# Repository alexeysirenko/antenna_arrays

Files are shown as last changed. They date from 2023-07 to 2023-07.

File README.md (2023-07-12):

# Комплект для використання KrakenSDR в польових умовах

Конструкція розроблялась в напівпольових умовах при відсутності нормальної майстерні, задля того щоб перевірити працездатність ідеї використання KrakenSDR для військових потреб, в тому числі задля перевірки точності. Через це конструкція має дещо кустарний вигляд (термоклей, ізолента тощо), але при цьому її легко відтворити маючи прямі руки і мінімум інструментів. При цьому все ще лишається великий простір для вдосконалення, наприклад непогано було б прикрутити герметичний Ethernet та силовий роз'єми до корпусу замість нерозборного варіанту з кабелями як зараз.

Комплект умовно ділиться на компоненти:
- <a href="/dipoles">Диполі (5+2) та фідерні лінії</a>
- <a href="/linear_array">Траверса та кріплення до мачти</a>
- <a href="/box">Гермобокс</a>

## Що можна покращити

- додати герметичні роз'єми для Ethernet та живлення (силовий роз'єм) на корпус, щоб кабелі легко було замінити
- примусове охолодження гермобокса. Самий простий варіант - кулер + терморезистор. Але це потрібно лише влітку, в інші пори року бокс має бути герметичним, тобто потрібна можливість закривати та відкривати воздухозаборники
- виніс траверси від мачти можна зробити на 50 мм далі
- потрібен режим енергозбереження. Простий варіант - реле, котре відключає подачу 220в на блок живлення KrakenSDR, управляється з пінів Raspberry
- передачу даних від Raspberry до клієнта можна зробити через модулі LoRa або Motorola+Bluetooth, тобто потрібен окремий пристрій, але він суттєво здешевить конструкцію (не потрібен буде Starlink)

## Галерея

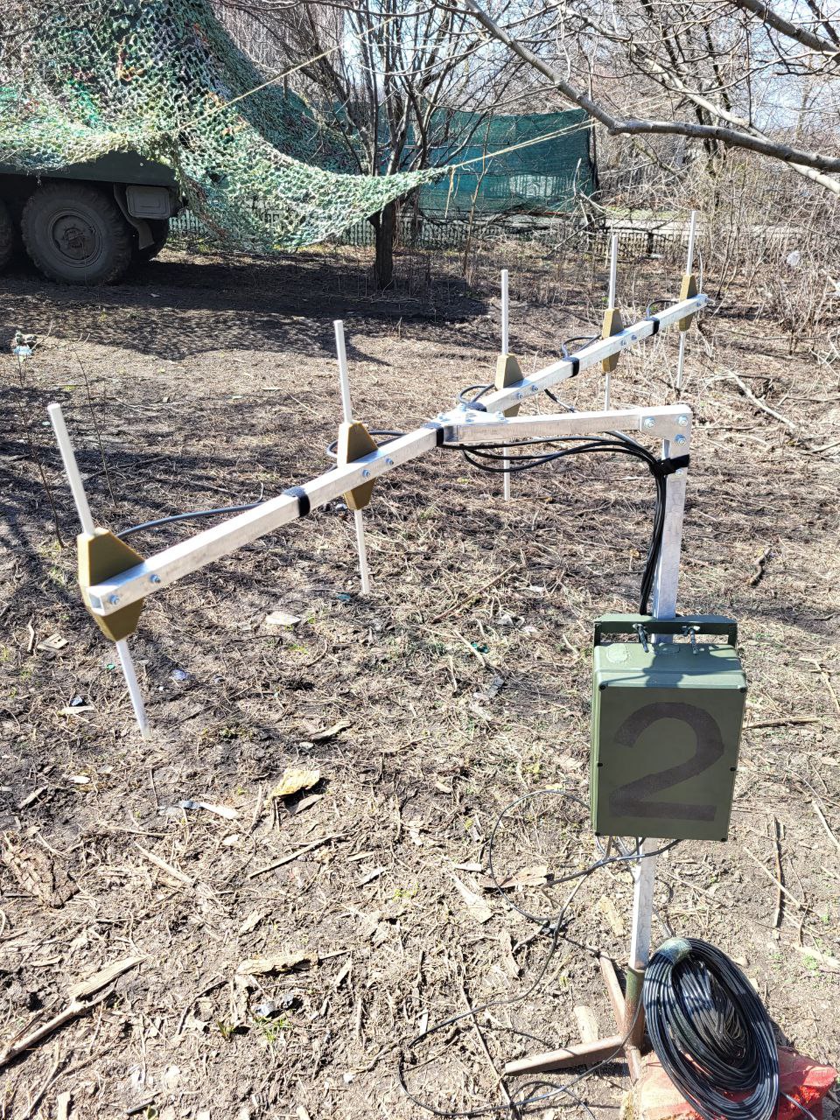
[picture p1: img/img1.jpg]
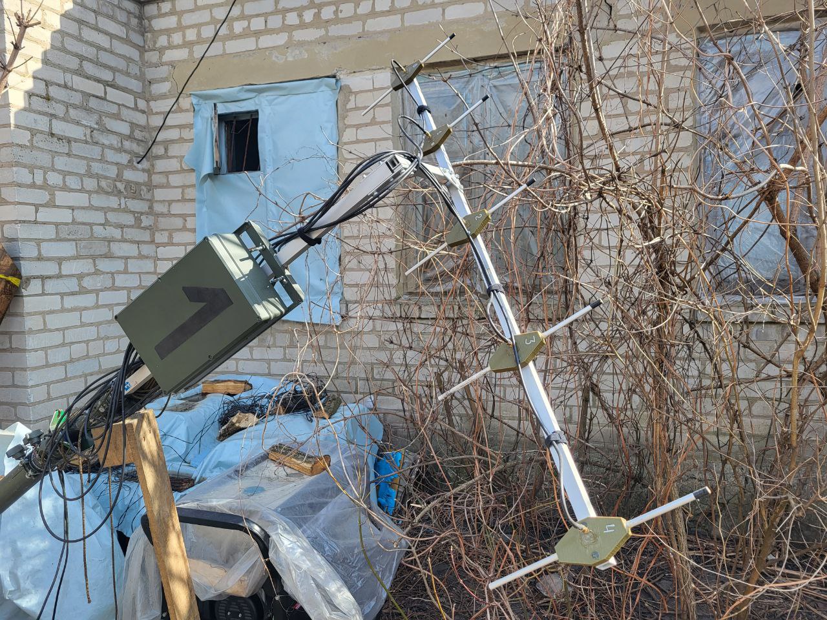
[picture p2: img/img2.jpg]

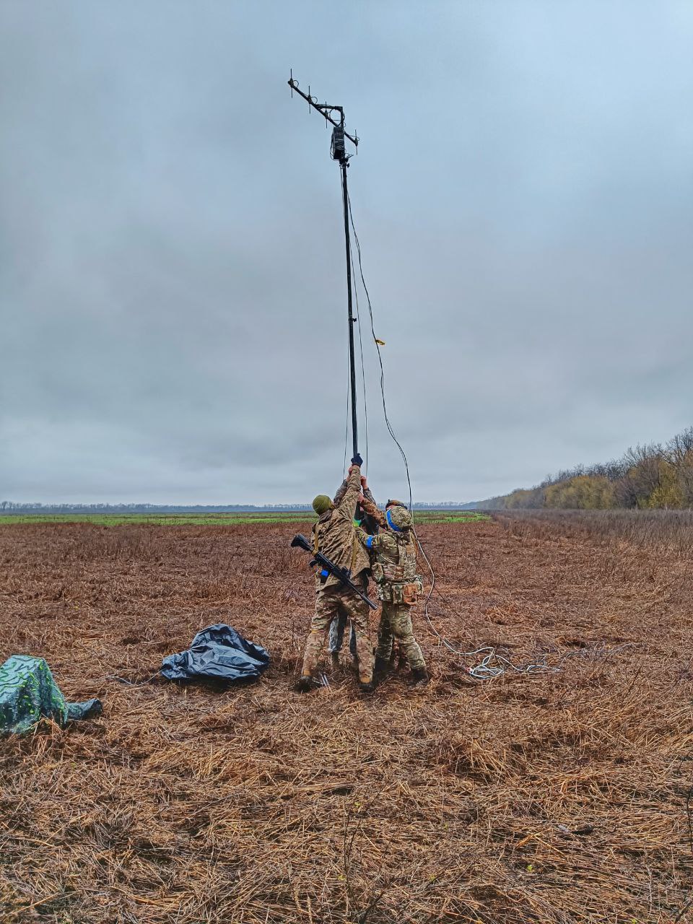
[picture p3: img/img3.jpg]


### Зауваження:

- Діполі на траверсі нумеруються зліва направо (від 0 до 4) якщо антена умовно стоїть перед вами і повернута до ворога
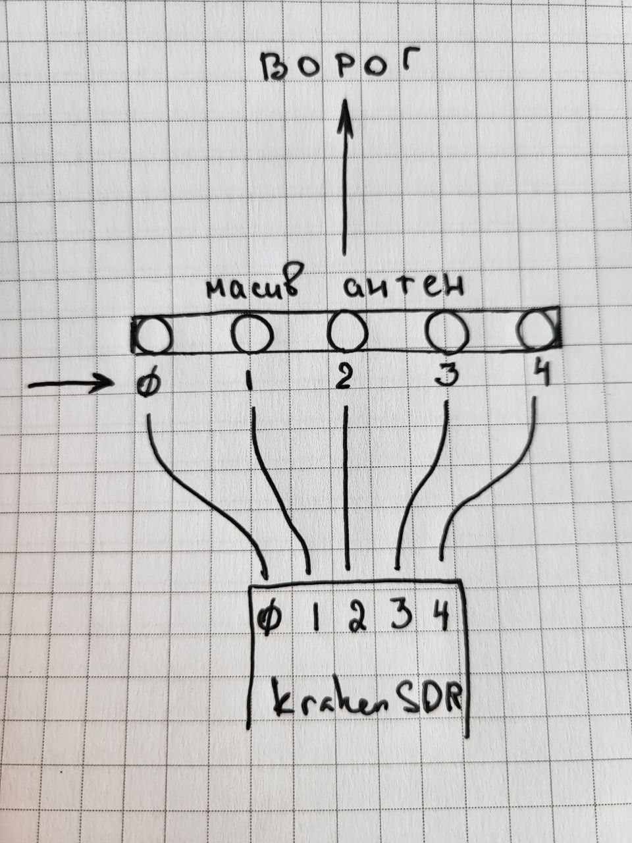
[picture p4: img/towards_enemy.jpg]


- Лінійний масив антен має парусність і крутиться за вітром - зробіть так щоб мачта не оберталась, бо траверса працює як флюгер
- Це додаткова причина частіше калібруватись (вираховувати кут антени до справжньої півночі), бо за ніч антена цілком може провернутись на 1-2 градуси
- Всі перешкоди між антеною та джерелом сигналу (будинки, дерева, рельєф) зменшують точність пеленгації

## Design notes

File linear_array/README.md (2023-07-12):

# Траверса та кронштейн (кріплення) до мачти

Кронштейн із траверсою, а саме виготовлення труб (деталі 1-3), вимагає слюсарних робіт. Виготовлення з'єднань між трубами (деталі 4-6) робиться лазерною порізкою (простіше за все), або також слюсарно

**Увага**. Дотрумуйтесь вказаних допусків при виготовленні траверси!

Листові елементи (з'єднання між трубами, деталі 4-5) виготовляються з листового алюмінію товщиною 3 мм. Деталь 6 (дистанційна вставка для переходу між трубою 25х25 та 20х20) виготовляється з листового алюмінію товщиною 5 мм

Всі елементи конструкції шліфуються для покращення адгезії (бо інакше фарба облізе миттєво), потім знежирюються, грунтуються (бажано) і фарбуються. Будете шліфувати - вдягніть респіратор, від болгарки палений цинк летить і він не дуже корисний для здоров'я якщо їм дихати.

Майте на увазі, що труби довше 1м Нова Пошта відправляє тільки на вантажні відділення.

## Траверса


## Виніс траверси


## Мачта


## Кріплення елементів між собою (лазерна порізка)

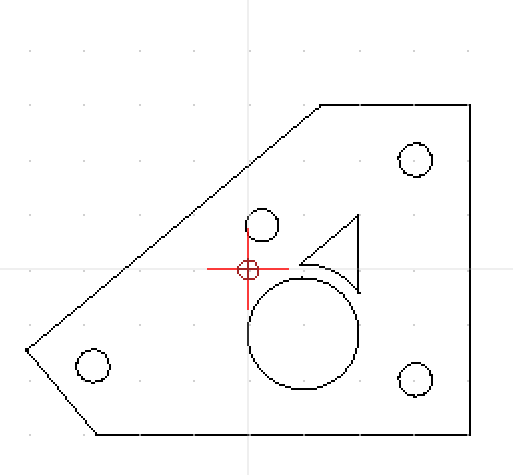
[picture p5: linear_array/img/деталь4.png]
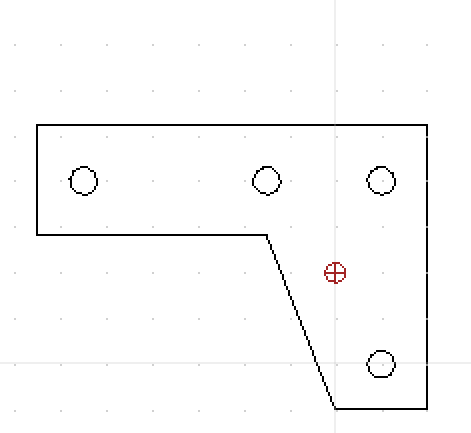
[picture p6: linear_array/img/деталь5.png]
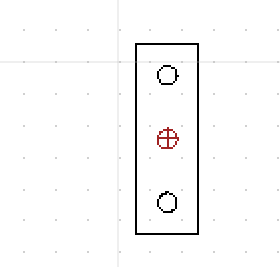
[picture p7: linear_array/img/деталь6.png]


## Скачати всі креслення одним архівом
<a href="linear_array.zip">Скачати креслення (DXF)</a>

## Галерея

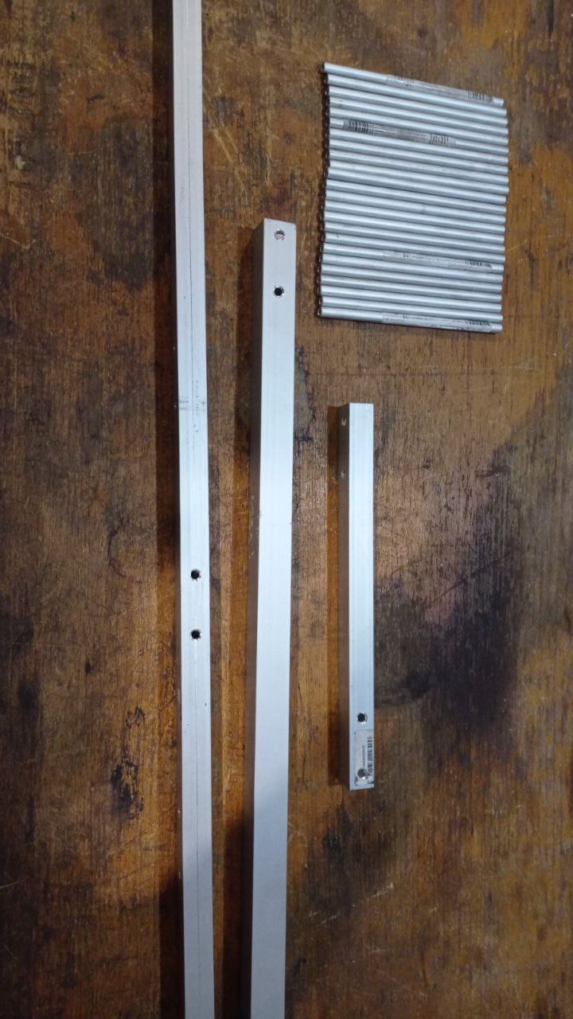
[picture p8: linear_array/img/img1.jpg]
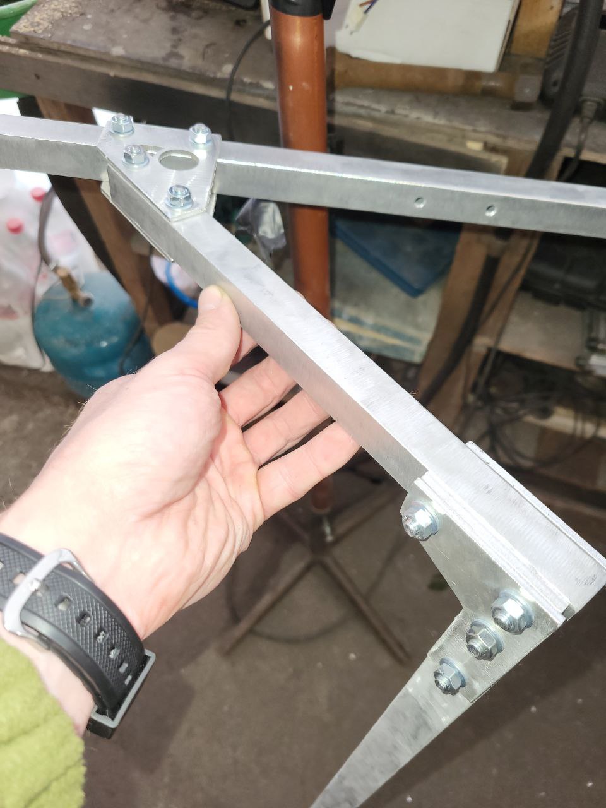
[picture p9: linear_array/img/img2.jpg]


## Де можна придбати елементи конструкції:

- ### Труба для траверси та виносу (деталі 1 та 2), 2м:
https://epicentrk.ua/ua/shop/truba-profilnaya-pryamougolnaya-alyuminiy-anodirovanoe-serebro-2-m-20x20x2x2000mm.html
https://epicentrk.ua/ua/shop/truba-profilnaya-kvadratnaya-alyuminiy-pas-2062-as-20x20x2x2000mm.html

- ### Труба для мачти (деталь 3), 1м:
https://epicentrk.ua/ua/shop/truba-profilnaya-kvadratnaya-alyuminiy-pas-2033-as-25x25x2x1000mm.html
https://epicentrk.ua/ua/shop/truba-profilnaya-pryamougolnaya-alyuminiy-anodirovanoe-serebro-1-m-25x25x1x1000mm.html

- ### Заглушка у трубу 20х20:
https://epicentrk.ua/ua/shop/zaglushka-vnutrennyaya-20kh20-pd.html

- ### Заглушка у трубу 25х25:
https://epicentrk.ua/ua/shop/zaglushka-kvadratnaya-chernaya-25kh25-mm-4-sht.html

- ### Болт М6х35 (4 шт)
https://epicentrk.ua/ua/shop/bolt-metricheskiy-din-933-6x35-mm-ves-expert-fix-85641.html

- ### Болт М6х40 (4 шт)
Можете купити саме ці що довші замість М6х35, потім по місцю вкоротити (зайвий метал близько до антен краще прибирати). Якщо вкоротите, зніміть фаску й оновіть різьбу, в полях або на морозі гайка має накручуватись швидко та без зусиль

https://epicentrk.ua/ua/shop/bolt-metricheskiy-din-933-6x40-mm-ves-expert-fix-85642.html

- ### Гайка М6
https://epicentrk.ua/ua/shop/gayka-shestigrannaya-m6-40-sht-expert-fix.html

- ### Шайба М6
https://epicentrk.ua/ua/shop/shayba-ploskaya-m6-40-sht-expert-fix.html

- ### Фарба 
RAL6006 мат, класіка

https://epicentrk.ua/ua/shop/emal-universalnaya-ral-6006-new-ton-khaki-olivkovyy-glyanets-400-ml.html

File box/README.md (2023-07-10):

# Гермобокс

Загерметизуйте всі отвори під кабелі, роз'єми і т.д.

## Галерея

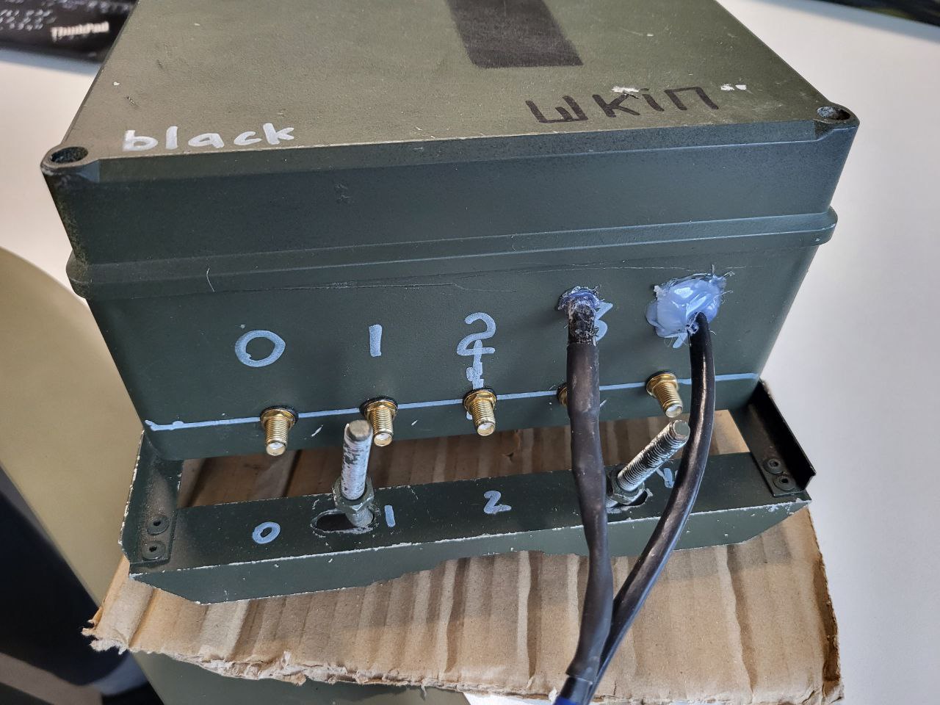
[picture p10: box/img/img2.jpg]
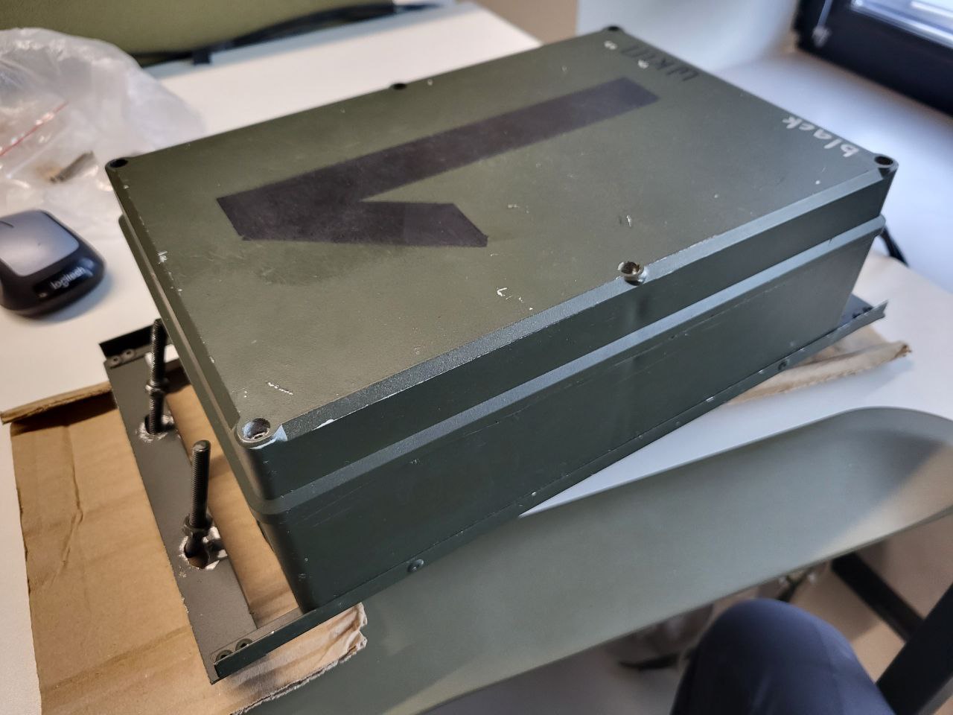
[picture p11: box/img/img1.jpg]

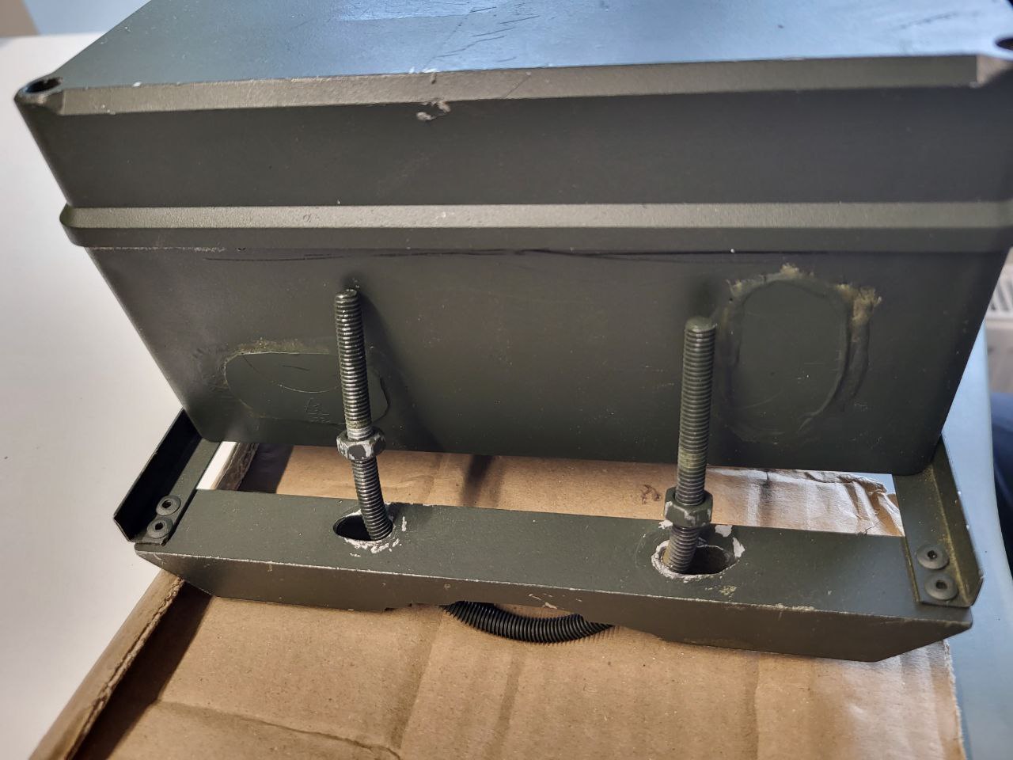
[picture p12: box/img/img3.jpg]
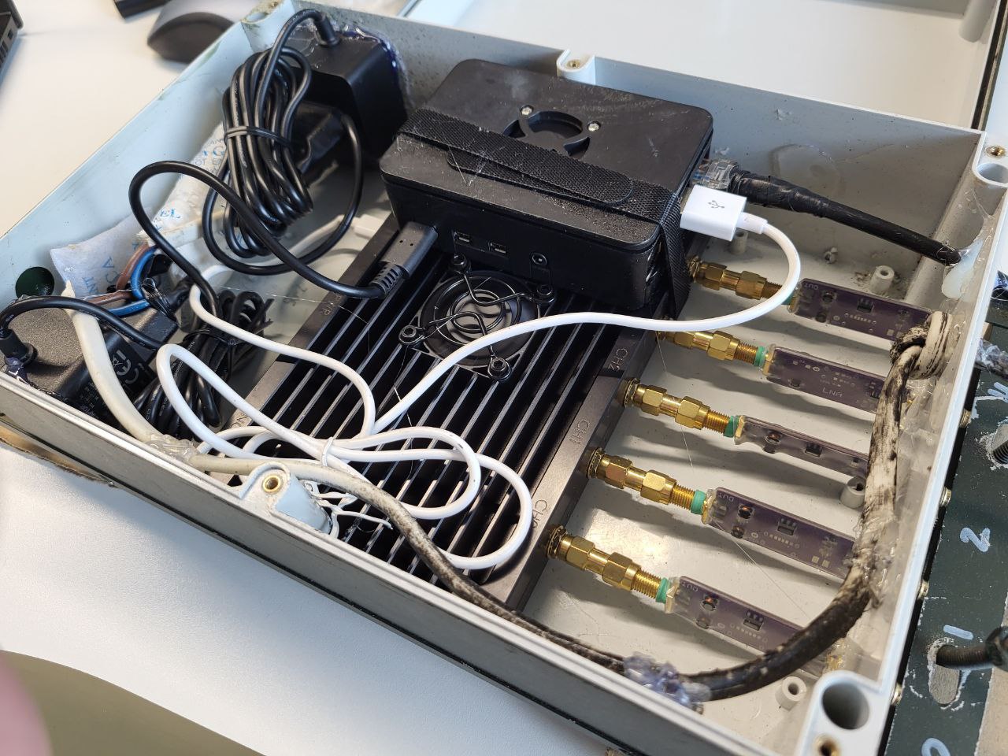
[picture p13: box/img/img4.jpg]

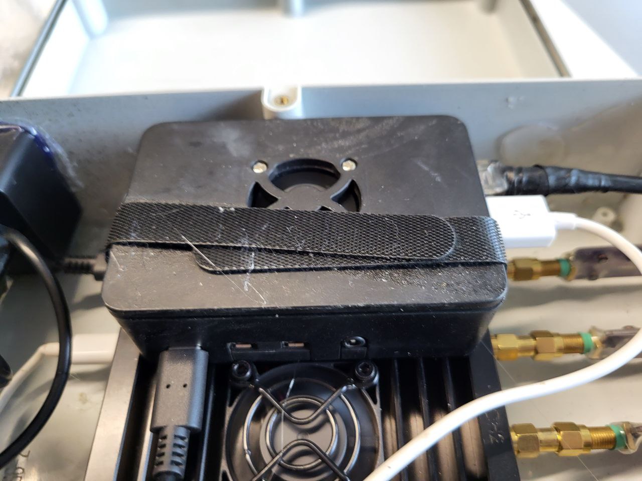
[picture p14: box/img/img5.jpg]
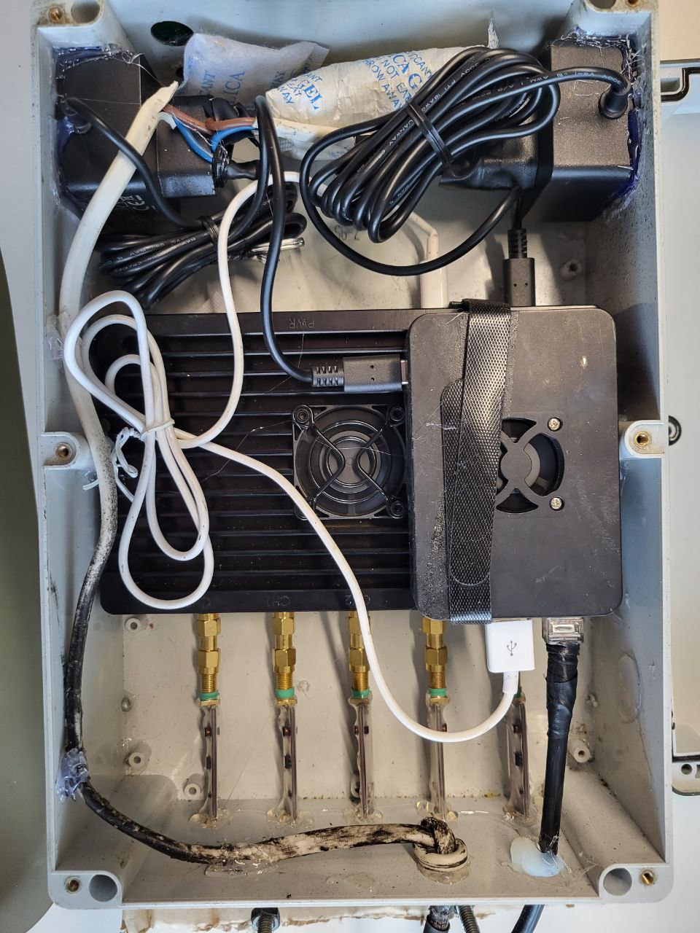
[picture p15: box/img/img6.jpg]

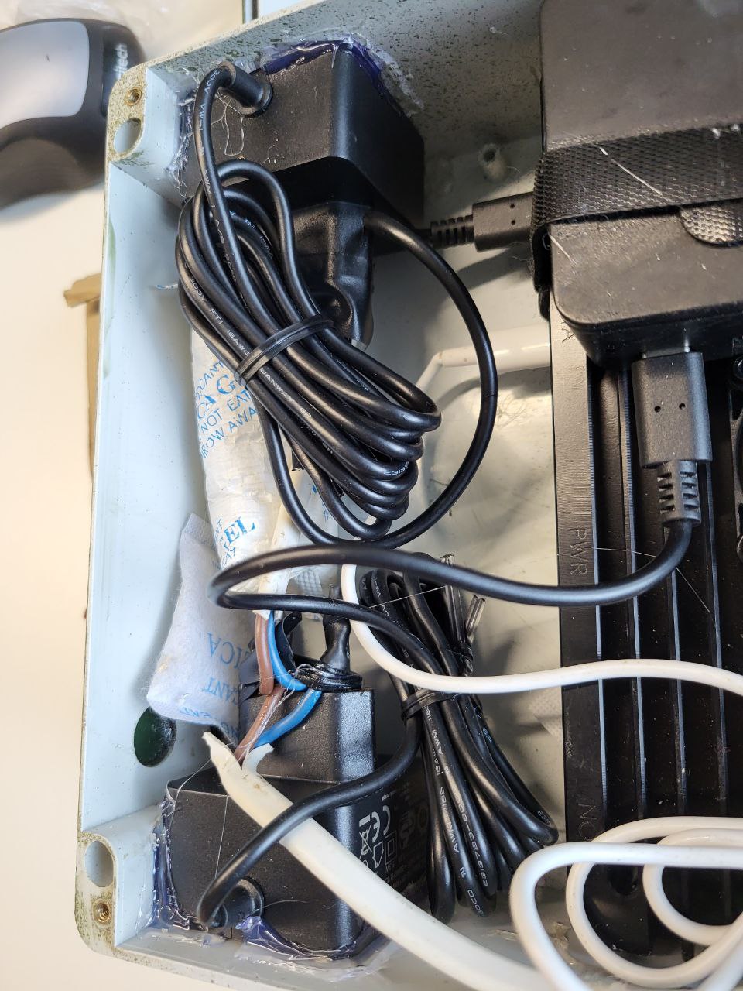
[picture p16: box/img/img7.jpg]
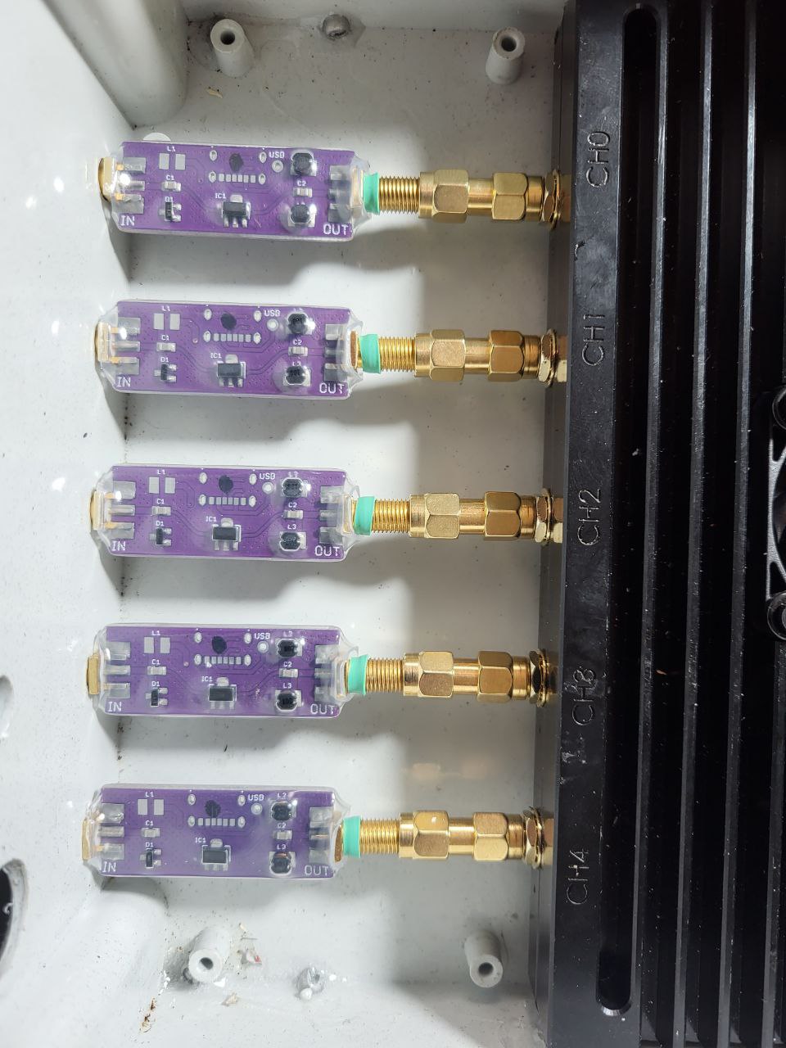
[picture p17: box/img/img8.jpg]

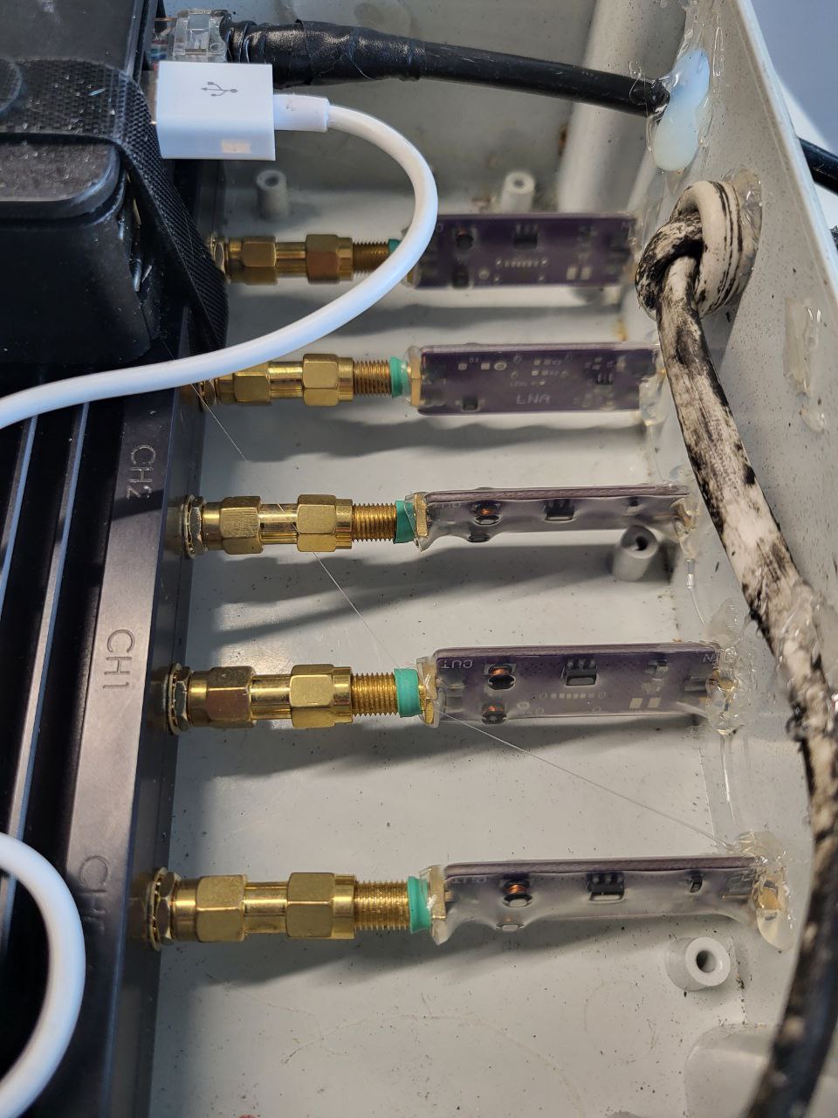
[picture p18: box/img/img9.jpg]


## Компоненти

### Блок живлення (потрібно 2 шт)
**Увага!** Беріть тільки оригінальний блок живлення Raspberry Pi 4. З іншими, навіть з достатньою потужністю, можна стикнутись з падінням напруги коли KrakenSDR включається та коли міняє частоту, це призводить до зависання та пошкодження файлової системи, доведеться ставити ОС заново
- https://evo.net.ua/ru/raspberry-pi-4-model-b-official-psu-black/

### Гермобокс
Вимагає допрацювання напильником щоб KrakenSDR став поперек корпусу, а також для кріплення до мачти (див. фото). Не забудьте загерметизувати всі отвори. Перед фарбуванням пройдіться ретельно наждаком по корпусу щоб покращити адгезію, інакше вся фарба швидко облізе. Якщо є пара пакетиків сілікагелю, то можете покласти всередину.
- https://www.rcscomponents.kiev.ua/product/z95jh-abs-kradex-korpus-svitlo-sirij-95x190x280mm-komplekt_131092.html

### LNA
Потрібно 5 штук як цей (можна без корпусу), краще на чипу Gali-39, він має давати нижчий фазовий шум. Живлення по BIAS-T, подача живлення вмикається на сторінці налаштувань KrakenSDR. Також в цього продавця ви можете замовити комплект із 5 фазово-симетричних кабелів для KrakenSDR із RG58 на заміну стандартних, просто акцентуйте увагу що потрібна фазова симетрія
- https://www.olx.ua/d/uk/obyavlenie/maloshumniy-pdsilyuvach-mshp-lna-0-7000-mgts-gali-39-IDRrIk7.html

### Перехідник від KrakenSDR до LNA
Потрібно 5 штук (не економте бо дешеві криві-косі, з недорізаною різьбою)
- https://kiev.prom.ua/ua/p1510478645-perehodnik-sma-vilka.html

### Кабель живлення у гермобокс 220 вольт 0.5мм^2 
Потрібно десь 30-35 метрів
- https://epicentrk.ua/ua/shop/provod-mnogozhilnyy-expert-power-shvvp-2x0-5-chernyy.html

### Патч-корд Ethernet 
35 метрів, можна 30
- https://rozetka.com.ua/powerplant_ca912643/p275820003/

### Грунт для пластику (опціонально)
- https://epicentrk.ua/ua/shop/mplc-grunt-dlya-plastiku-belife-primer-plastic-400-ml-chornii-ral9005-1ece0c1f-b65b-6742-bf34-dbc76f3f442f.html

### Фарба
RAL 6006 мат Олива
- https://epicentrk.ua/ua/shop/emal-universalnaya-ral-6006-new-ton-khaki-olivkovyy-glyanets-400-ml.html

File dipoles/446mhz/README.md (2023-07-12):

# Зборка диполів

## Готовий диполь:
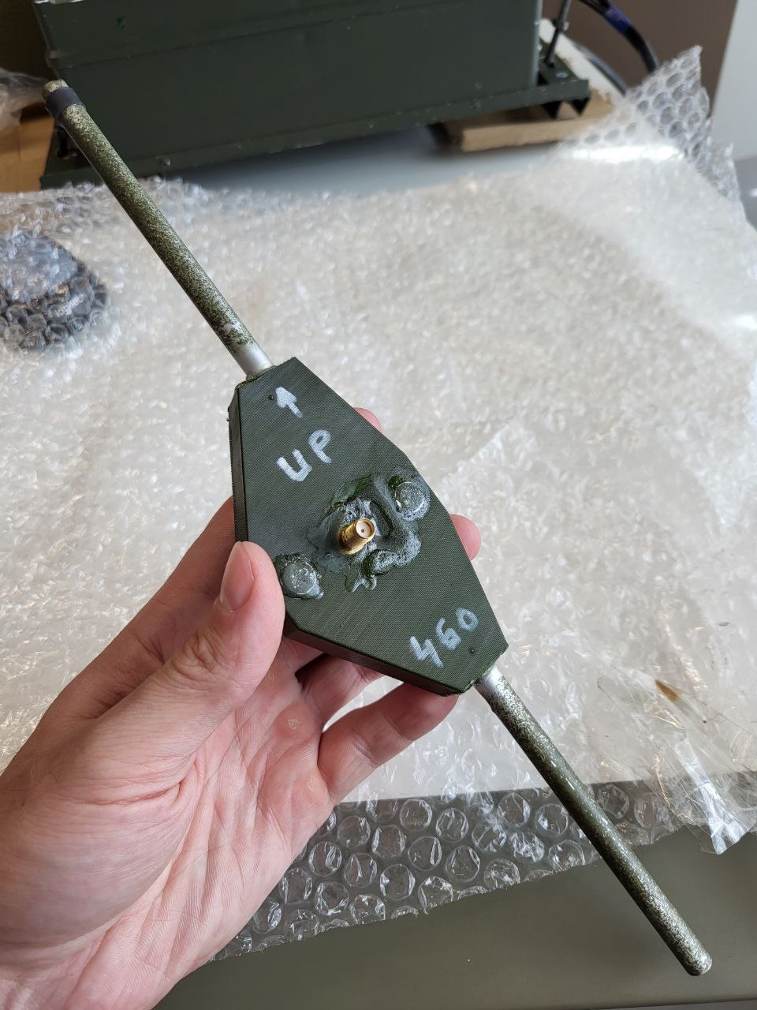
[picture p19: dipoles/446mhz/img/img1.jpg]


## Корпус диполя:

<a href="корпус_диполя_3D_друк.zip">Скачати модель корпуса диполя під 3D-друк</a>

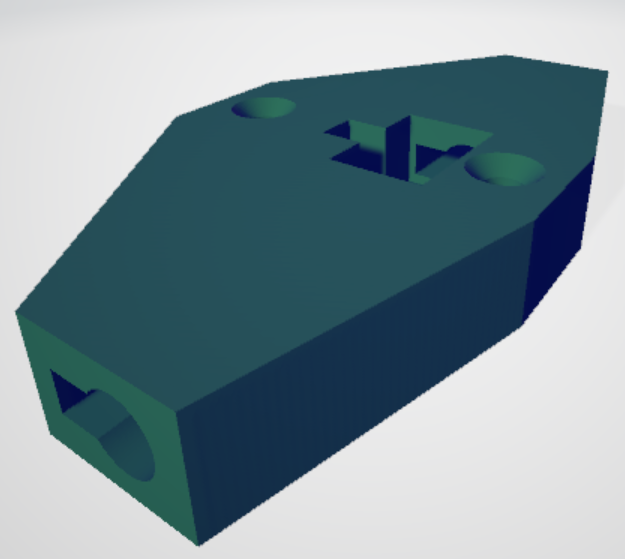
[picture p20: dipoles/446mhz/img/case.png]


## Плече диполя (резонанс ~446 МГц)

<a href="плече_диполя.zip">Скачати креслення в форматі DXF</a>



Відео із зауваженнями по зборці:
https://youtu.be/QFiHPVZvDwM

Необхідна кількість - 5 шт. Бажано зробити 7 шт (1 зламається, 1 загубиться, потім зробити такий самий буде важко)

## Необхідний інструмент, в тому числі:
- антенний аналізатор
- паяльний фен + паяльник + припой + каніфоль + флюс для [пайки алюмінію](#soldering) 
- клей цианокрилат двокомпонентний
- знежирювач (спирт)

## Необхідні деталі:
- корпус диполя (3d-друк, темно-зелений пластик) та кришки до нього
- алюм. трубки для плеч диполей (див. креслення)
- гвинти М5х40 (плоска шляпка) та гайки

## Порядок зборки:
- трубка диполя шліфується надфілем в місці пайки таким чином, щоб утворилась пласка ділянка 1х3 мм, що доходить до края трубки
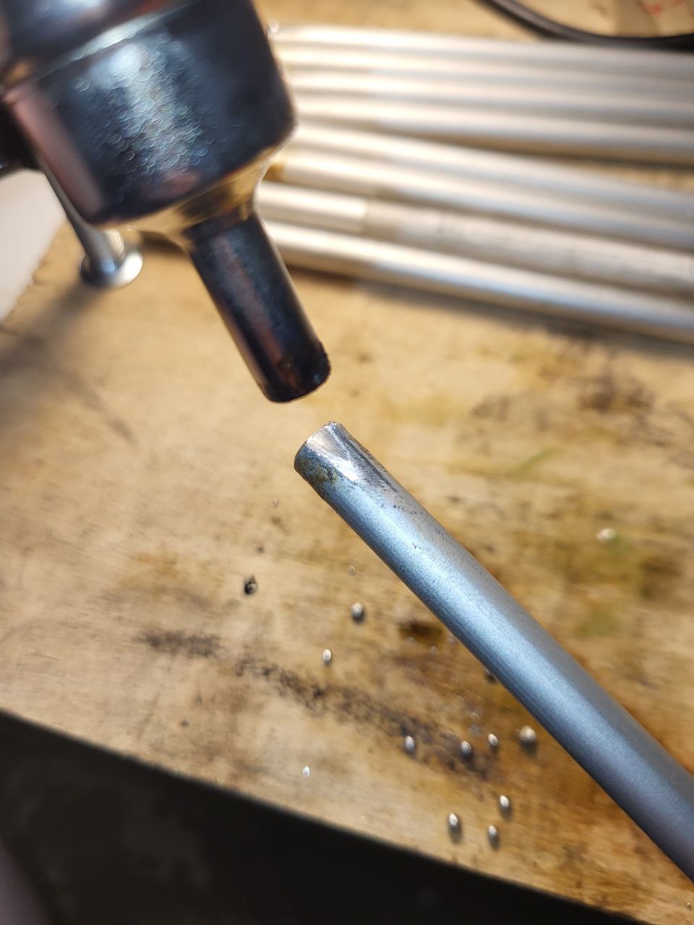
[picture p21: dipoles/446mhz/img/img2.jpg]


- на 2 трубки наноситься припой (щодо тонкощів [пайки алюмінію](#soldering) див. нижче). Пропаяна ділянка має доходити до края трубки. Якість пайки перевіряється механічним чином - спробуйте її зірвати легкими продольними ударами по припою вздовж вісі трубки
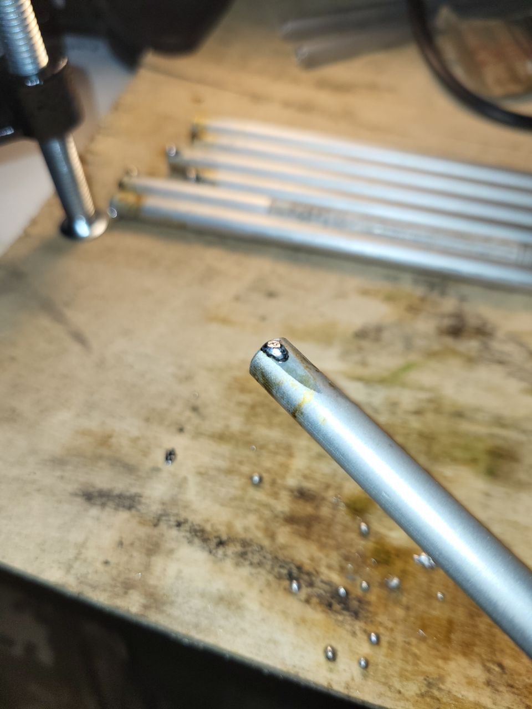
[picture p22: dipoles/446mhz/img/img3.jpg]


- від роз'єму відламуються зайві лапки контактів таким чином, щоб лишився центральний контакт та верхній контакт зі сторони трубки-екрану, потім залужуються
- роз'єм, трубки та корпус диполя знежирюються спиртом, залишки флюсу прибираються
- роз'єм вставляється в посадочне місце в корпусі диполя. Перевіряється що стоїть рівно (вісь різьби перпендикулярно корпусу, сам роз'єм щільно прилягає до стінок)
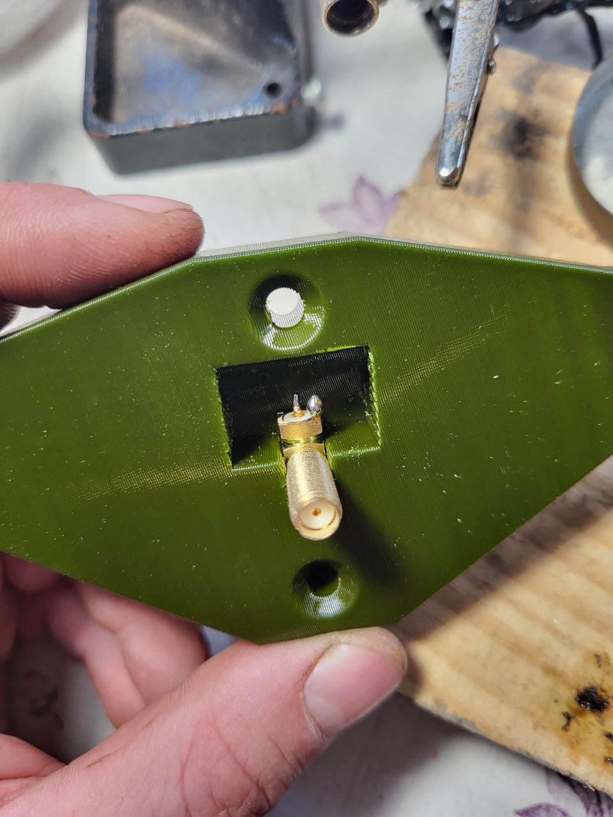
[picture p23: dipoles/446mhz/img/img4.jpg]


- вставляється трубка що має з'єднуватись з центральною жилою (дивись на положення упора в корпусі котрий задає зазор між трубками). Якщо трубка сидить в отворі дуже нещільно і випадає, витягніть її та гарячим паяльником зробіть 3 канавки (під кутом ~120 градусів одна до одної) з торця отвору під трубку
- трубка припаюється до центральної жили
- таким же чином припаюється трубка до екрану

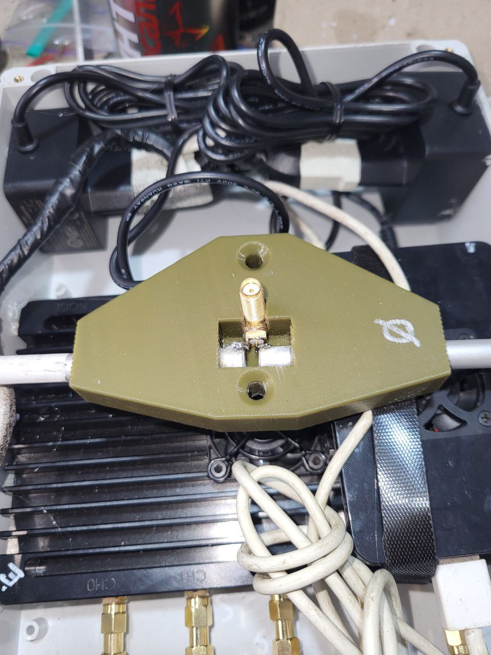
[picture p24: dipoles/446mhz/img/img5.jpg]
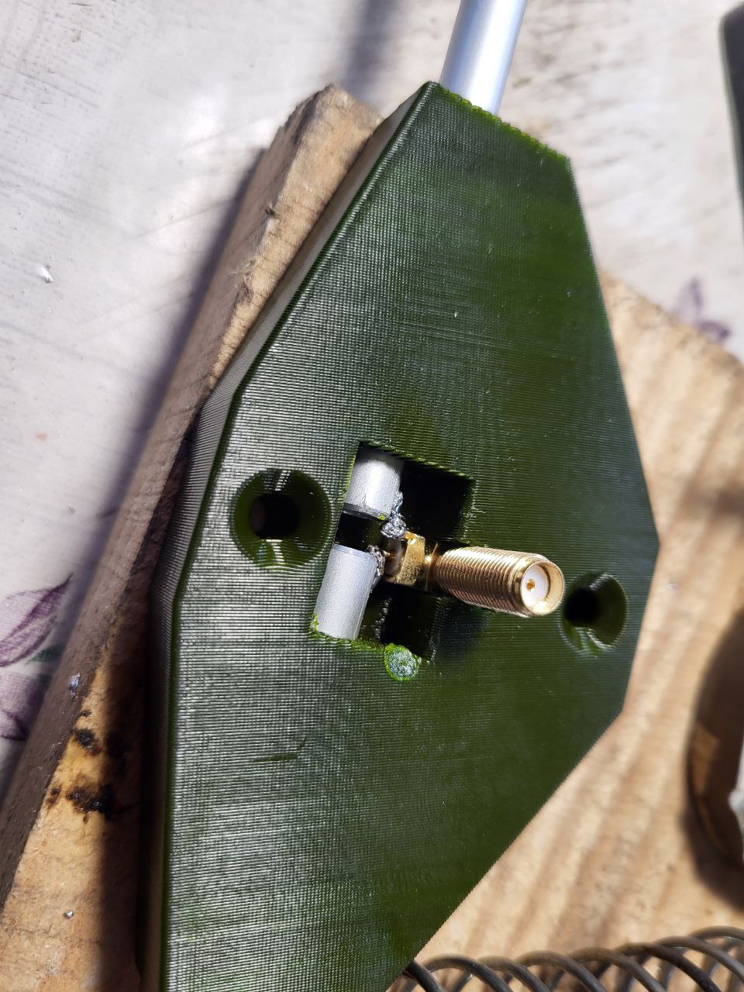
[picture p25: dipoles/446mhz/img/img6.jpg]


- обидві трубки та роз'єм фіксуються невеликою кількістю цианокрилата щоб уникнути механічного пошкодження
- диполь перевіряється антенним аналізатором, порівнюється з іншими диполями, по необхідності переробляється
- трубка котра відповідає центральній жилі маркується, наприклад кільцем з термоусадки не клеєвій основі 5-10 мм довжиною. Це необхідно щоб **_під час кріплення на траверсу всі диполі дивились центральною жилою (плечем) вгору_**

**_Кожен диполь має бути герметичним. Всі диполі мають мати фазову симетрію_** , що має проявлятись в т.ч. у резонансі на одній й тій самій частоті. Порядок перевірки диполів:
- закріпляєте траверсу стаціонарно горизонтально, бажано подалі від металевих конструкцій
- по черзі прикручуєте диполі до однієї точки на траверсі, під'єднуєте одним і тим самим фідером (1.5м+), відходите з антенним аналізатором якнайдалі та міряєте частоту резонансу
- розбіжність частоти резонансу між диполями має бути в межах 1 МГц

Основна причина розбіжності по частоті між диполями - різний зазор між трубками. Переконайтесь що обідві трубки торкаються стопора в корпусі, за необхідністю перепаяйте. Також завелика кількість припою на одній із трубок може вплинути на частоту резонансу.

## Фінальна зборка:
- роз'єм та трубки диполя повноцінно приклеюються до корпуса зсередини
- в корпус вставляється пластикова кришка котра прикриває місце пайки
- проклеюються всі стики диполя (кришка, навколо роз'єму, навколо трубок, торці трубок за необхідністю), диполь має бути повністю герметичним

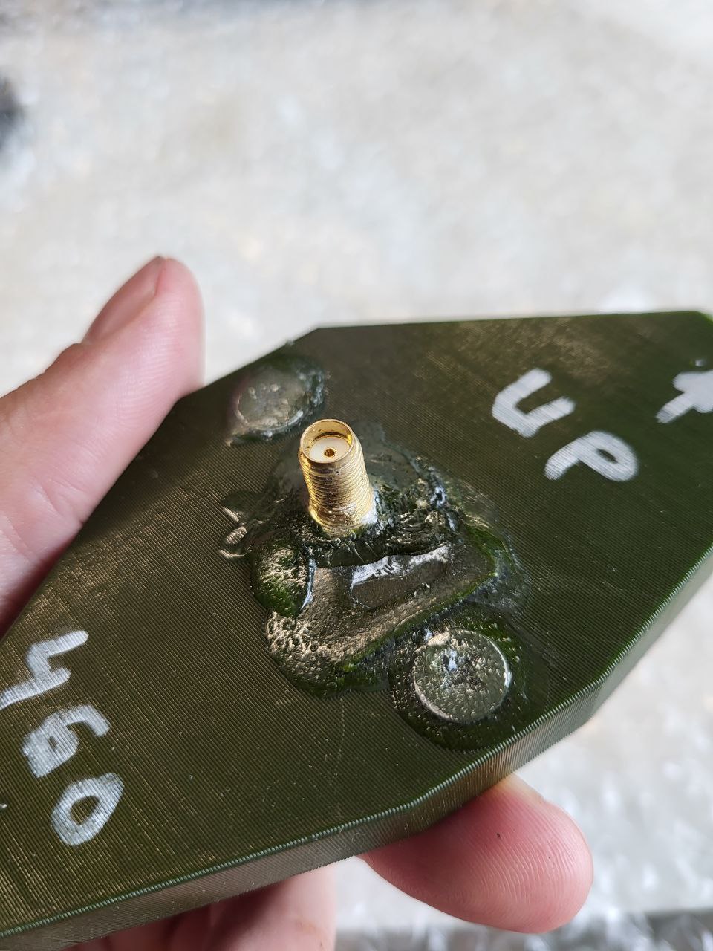
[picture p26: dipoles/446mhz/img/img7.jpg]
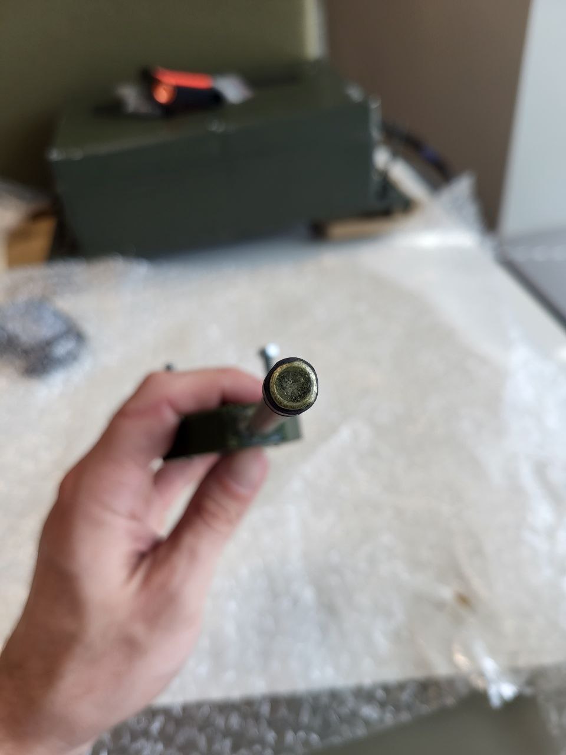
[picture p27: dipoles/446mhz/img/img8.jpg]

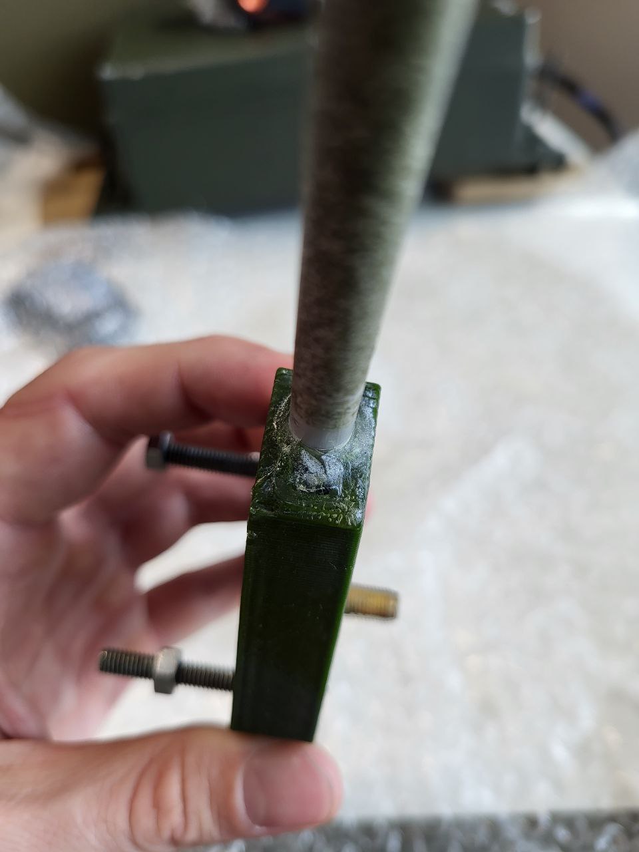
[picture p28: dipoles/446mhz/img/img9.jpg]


- отвори у корпусі під гвинти для кріплення до траверси просверлюються свердлом ф5 (може з'їхати міжосьова відстань після 3д-друку)
- гвинти М5х40, попередньо пофарбовані та знежирені, вставляються в отвори та фіксуються в корпусі цианокрілатом (різьба та шляпка)
- блискучі елементи диполя (трубки) вкриваються **тонким** шаром фарби, вважай "бризкаються", щоб крізь фарбу проступав метал. Велика кількість фарби потенційно може привести до відхилення в показниках роботи антени через наявність у фарбі металів.
- на гвинти накручуються гайки М5


##  Пайка алюмінія

- Потрібна паяльна станція з феном, або просто паяльний фен, інакше трубку важко прогріти і вона швидко охолоджується
- З власного досвіду звичайний припоєм ПОС-61 паяється краще ніж низькотемпературними з додаванням срібла
- Непогано себе зарекомендував ось такий флюс
https://prom.ua/ua/p577055255-flyus-pasta-dlya.html

### Порядок дій при пайці (мій досвід):
- Трубку зажимаєте у тисках
- Жало паяльника вставляєте в протилежний від місця пайки кінець трубки, щоб не давати їй охолоджуватись
- Феном грієте місце пайки
- Наносите флюс і максимально швидко, поки флюс не вигорів, підносите проволочку припою так, щоб на зашліфованій ділянці утворилась крапля. Продовжуєте гріти феном
- Крапля можє не прилипнути відразу. Продовжуєте гріти феном, наносите флюс зверху краплі. З кожним нанесенням крапля буде краще і краще змочувати місце пайки. Старайтесь наносити флюс так, щоб крапля змочила торець трубки, тобто не було зазору між торцем і місцем пайки
- Залишаєте пропаяну трубку охолоджуватись, потім перевіряєте місце пайки на міцність легкими продольними ударами по припою, наприклад, обухом ножа

## Де можна придбати елементи конструкції (приклад):

Роз'єм SMA ("Разъем SMA-F KWHD Female на плату 90 град. L=23mm")
- https://www.nikom.biz/product_A145029.html
- https://voron.ua/catalog/035346--razem_sma-f_kwhd_female_gnezdo_na_platu_90_grad?lang=ru (використовував саме такий)
- https://prom.ua/ua/p1544436475-razem-sma-kwhd.html (саме цей я не тестував на відповідність отвору в корпусі, але має підійти)

Цианокрілат двокомпонентний
- https://epicentrk.ua/ua/shop/mplc-klei-akfix-705-shvidkogo-skleyuvannya-400-ml-1eb96a36-9013-614c-a259-4fa76f03cc38.html

Труба для диполів:
- https://epicentrk.ua/ua/shop/truba-profilnaya-kruglaya-alyuminiy-anodirovanoe-serebro-1-m-d8x8x8x1x1000mm.html

Кришка на плече (трубку) диполя:
- https://epicentrk.ua/ua/shop/mplc-zagluska-krugla-zovnisna-8-mm-10-st-cornij-rdn-8-blk-107-1edb114c-0526-6c6c-89f2-7972dc888971.html
- https://epicentrk.ua/ua/shop/mplc-zagluska-dla-otvoriv-8-mm-10-st-cornij-to-8-blk-203-1edc6fe8-dec7-602e-9e7a-c9732497d757.html

Гайка М5 для кріплення диполя до траверси (барашкові не можна, бо резонанс попливе):
- https://epicentrk.ua/ua/shop/gayka-shestigrannaya-m5-40-sht-expert-fix.html

Гвинт М5х40, на 5 диполів потрібно 10 штук, відповідно 2 упаковки:
- https://epicentrk.ua/ua/shop/vint-metricheskiy-din-965-5x40-mm-8-sht-expert-fix.html

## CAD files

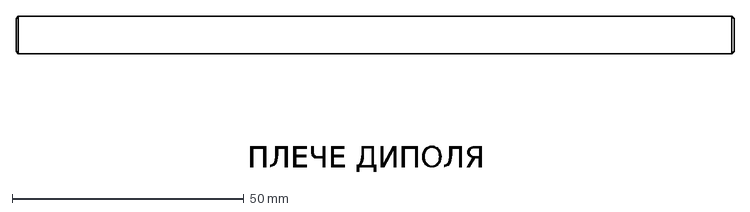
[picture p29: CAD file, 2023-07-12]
dipoles/446mhz/плече_диполя.dxf
ПЛЕЧЕ ДИПОЛЯ

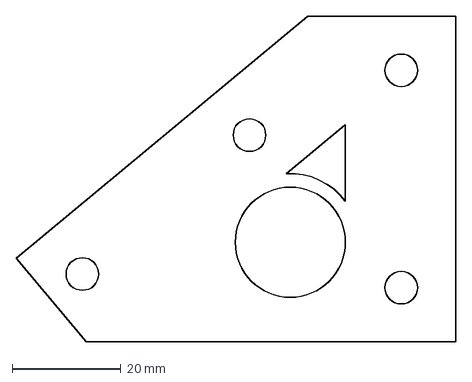
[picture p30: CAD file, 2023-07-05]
linear_array/лазер/part4-лазер-трикутник.dxf
80.8 x 60.0 mm

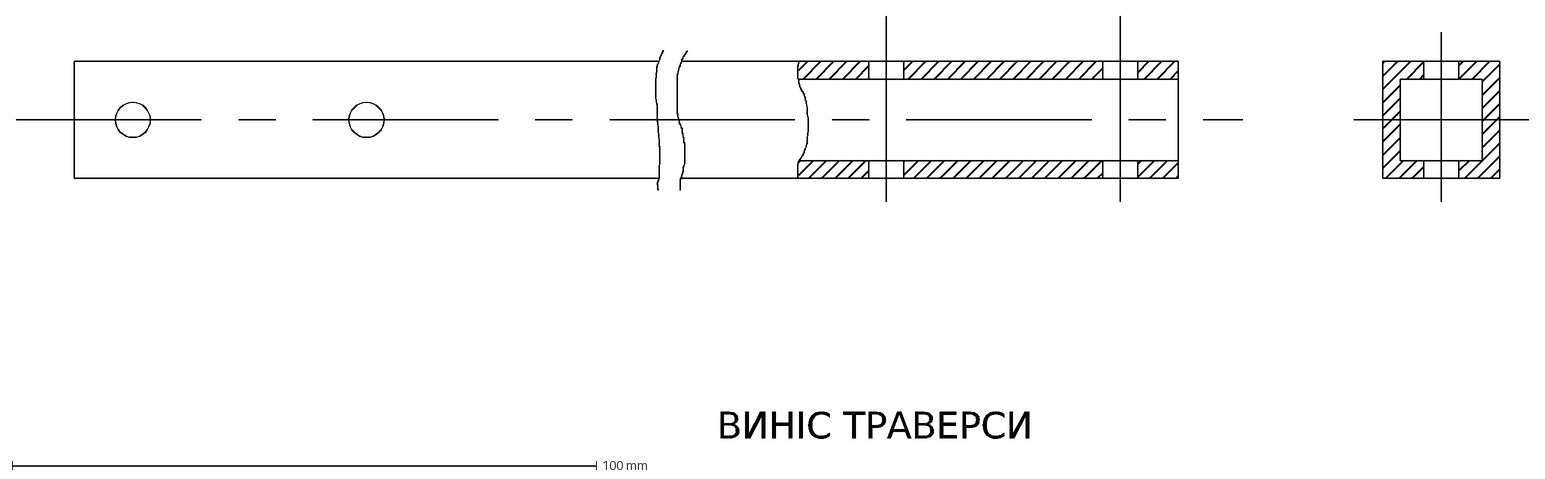
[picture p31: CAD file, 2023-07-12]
linear_array/слюсарні_роботи/виніс.dxf
ВИНІС ТРАВЕРСИ

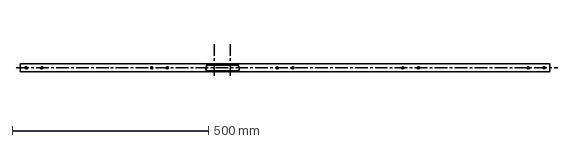
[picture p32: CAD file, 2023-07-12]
linear_array/траверса.dxf
1380.0 x 80.0 mm

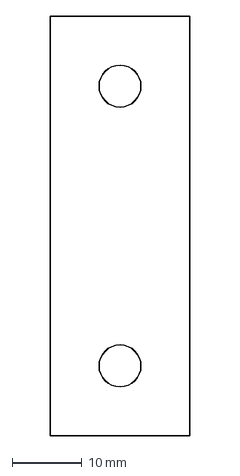
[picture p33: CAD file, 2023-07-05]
linear_array/лазер/part6-лазер-вставка.dxf
20.0 x 60.0 mm

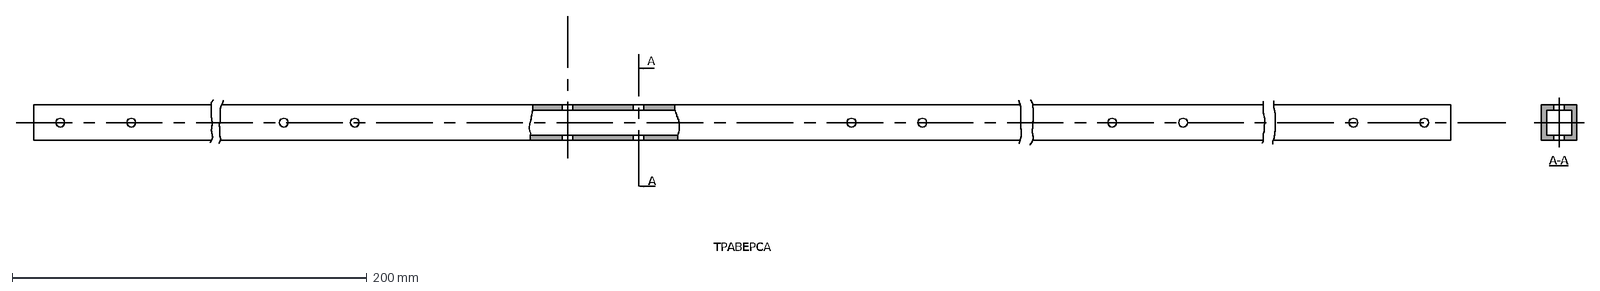
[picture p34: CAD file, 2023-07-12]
linear_array/слюсарні_роботи/траверса_short.dxf
A-A
A
ТРАВЕРСА

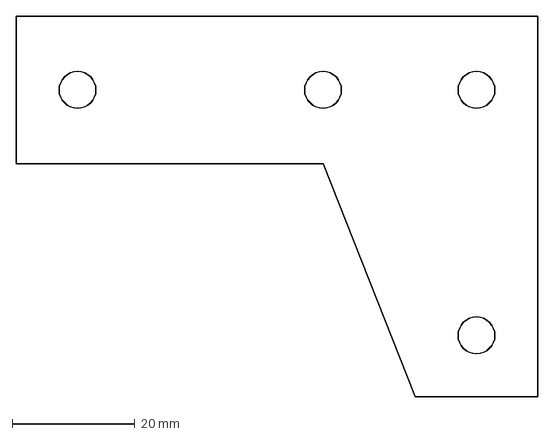
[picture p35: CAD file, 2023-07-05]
linear_array/лазер/part5-лазер-Г-подібна.dxf
85.0 x 62.0 mm

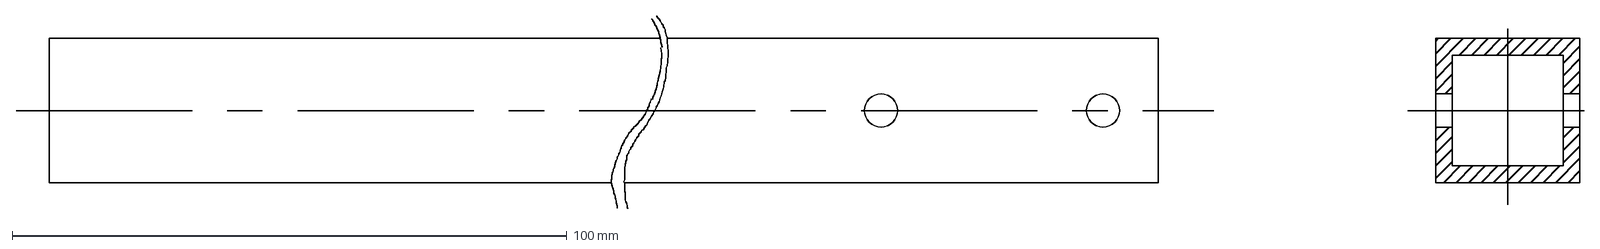
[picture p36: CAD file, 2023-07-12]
linear_array/слюсарні_роботи/мачта.dxf
282.8 x 34.8 mm

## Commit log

2023-07-05 Add drawing of the mast
    [part4-лазер-трикутник.dxf, part5-лазер-Г-подібна.dxf, part6-лазер-вставка.dxf]
2023-07-08 Add dipole assembly instructions
    [корпус_диполя.stl, корпус_диполя_source.FCStd, кришка_диполя.stl]
2023-07-10 test image 3
    [корпус_диполя.stl, корпус_диполя_source.FCStd, кришка_диполя.stl]
2023-07-10 test image 10\4
    [part4-лазер-трикутник.dxf, part5-лазер-Г-подібна.dxf, part6-лазер-вставка.dxf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]
2023-07-10 test image 165
    [part4-лазер-трикутник.dxf, part5-лазер-Г-подібна.dxf, part6-лазер-вставка.dxf]
2023-07-12 Add dxf drawings
    [виніс.dxf, мачта.dxf, плече_диполя.dxf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]
2023-07-12 Плече диполя
2023-07-12 Плече диполя креслення
    [part4-лазер-трикутник.dxf, part5-лазер-Г-подібна.dxf, part6-лазер-вставка.dxf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]
2023-07-12 Плече диполя - виправив лінку
2023-07-12 Зображення диполя
2023-07-12 Плече диполя креслення 2
2023-07-12 Що можна покращити
